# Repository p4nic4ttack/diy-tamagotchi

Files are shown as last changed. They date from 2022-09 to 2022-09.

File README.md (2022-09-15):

# DIY Tamagotchi
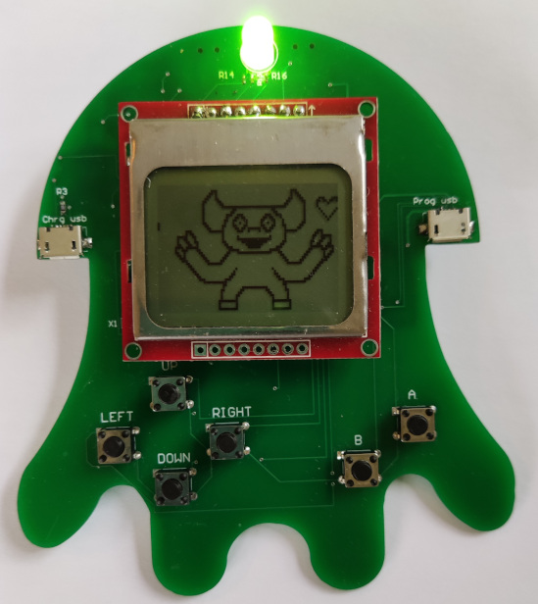
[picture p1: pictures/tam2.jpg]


## Project introduction
This project features a 'home made' DIY Tamagotchi. <br>The aim was to create a virtual pet for which the user needs to care in order to maintain its general happiness. Caring for the Tamagotchi is done by feeding and washing it on a regular basis or by playing games with it.<br>
This README.md covers the technical details of this project and the issues I ran into.
### Content
* [Main components](#main-components)
* [Software features](#software-features)
* [Hardware features](#hardware-features)
* [How does the hardware works?](#how-does-it-work-hw)
 * [Power Supply](#how-does-it-work-hw-power)
 * [Programming interface for the XC888](#how-does-it-work-hw-programming)
 * [RTC support](#how-does-it-work-hw-rtc)
 * [Hardware blockdiagram](#hw-blockdiagram)
* [Hardware issues](#hw-issues)
 * [Inductor does not let enough current pass through](#hw-issues-inductor)
 * [Battery lifetime](#hw-issues-battery)
 * [Minor issues](#hw-issues-minor)
* [How does the software works?](#how-does-it-work-sw)
 * [Software development](#how-does-it-work-sw-dev)
 * [Bitbanged interfaces](#how-does-it-work-sw-bitbanging)
 * [Interrupt based time intervals](#how-does-it-work-sw-isr)
 * [Software blockdiagram](#sw-blockdiagram)
* [Software issues](#sw-issues)
 * [Battery lifetime](#sw-issues-battery)
 * [Memory models](#sw-issues-memory)
* [Putting everything to work](#putting-it-to-work)

### Main components
The following main components were used in order to realise this:
- XC888 micro controller (8051 family)
- Nokia 5510 LCD display
- DS1307 for RTC support
- 3.7V LiPo battery
- RGB status LED
- 6 press buttons for navigation

Note that the complete component list can be found in the BOM [here](pcb-design-Altium/bom.csv).

### Software features

Technical:
 - Small Device C Compiler aka sdcc
 - Mix of assembly & C
 - Bitbanged I²C & SPI interfaces
 - Interrupt based time interval
 - Animations based on 'diffs'
 - Views (state machines)

<br>

Functional:
 - 2 types of pets
 - Time/clock
 - Emotion shown by the virtual pet and on the RGB LED
 - Sleep time between 8 pm and 9 am
 - Satisfaction/emotion depends on care
 - Feeding, washing, playing a game

### Hardware features
- XC888 micro controller (8051 family)
- LiPo powered
 - Battery charging circuit on board
 - Overcharge, overdischarge & overcurrent protection
- Reprogrammable (FT232RL using micro USB)
- RTC via DS1307 (32.76KHz)
- Navigation press buttons
- Status RGB LED
<br>
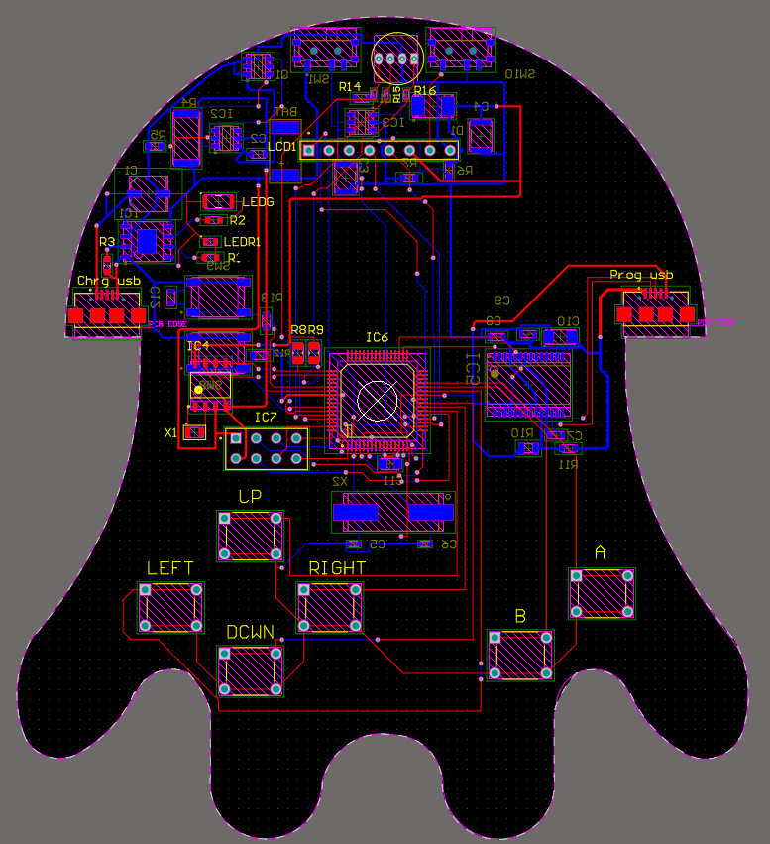
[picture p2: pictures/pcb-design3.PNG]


## How does the hardware works?

### 1. Power suppy
The circuit is powered by a 3.7V LiPo battery. Since most components need 5V to function, it was necessary to use a step-up IC (MT3608) to get 5.1V.
<br>
The battery can be charged through a micro USB port which is connected to a charging IC (TP4056). This charging IC is connected to battery protection IC (FS312F-G) which protects for overcharge and overdischarge. Note that the two necessary MOSFETS are externally attached for this.

### 2. Programming interface for the XC888
In order to program the XC888, an FT232RL is used which is connected to the right side micro USB port. For sake of simplicity two micro USB ports are present, one for Programming and one for charging. This could also be done with one micro USB port.

### 3. RTC support
RTC is done through the DS1307 IC. This IC communicates with the XC888 using I²C. Since the XC888 has no native I²C support, it was necessary to bitbang this on the XC888.<br>
Note that the SDA and SCL pins are open drains, which means that external pull up resistors are normally necessary. Since the XC888 provides internal pull ups on its pins, it wasn't necessary to provide external pull ups, although they are still there in my design.

### Hardware block diagram
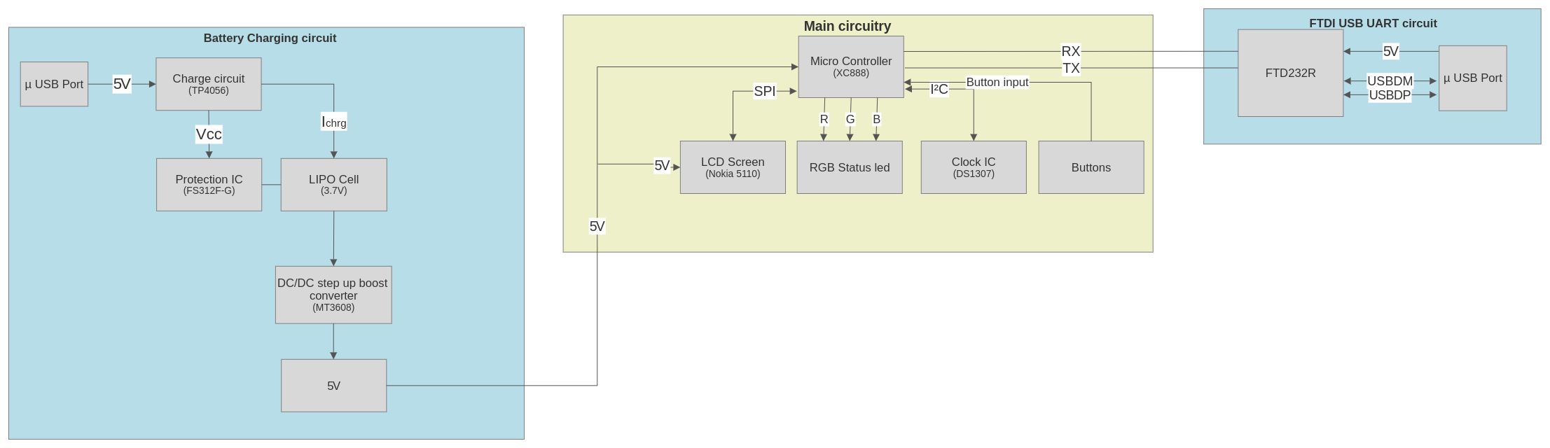
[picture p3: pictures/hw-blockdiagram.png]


(See [schematics](pcb-design-Altium/schematics.pdf))

## Hardware issues

### 1. Inductor does not let enough current pass through
When enabling the backlight of the Tamagotchi LCD screen, the inductor (L1) used in the step up circuitry does not let enough current pass. When enabling the backlight for a longer time, the inductor will start burning as seen in the pictures below:<br>
<p align="center">
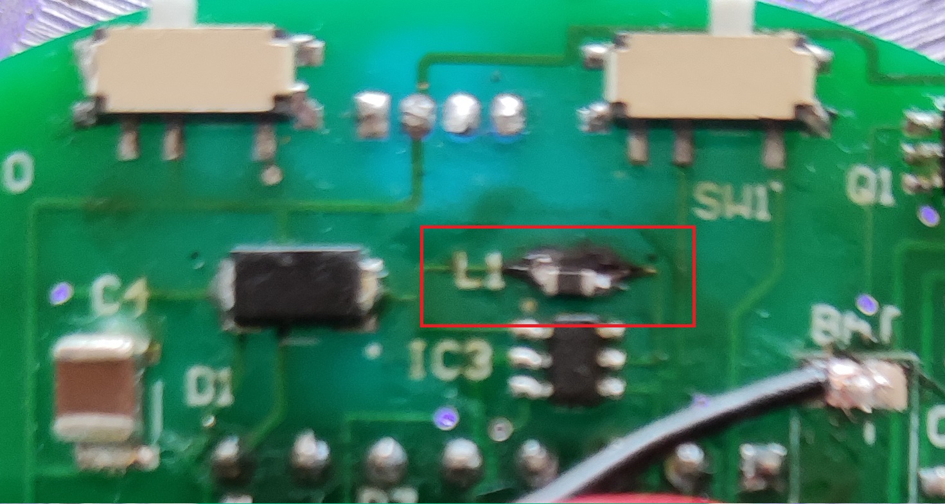
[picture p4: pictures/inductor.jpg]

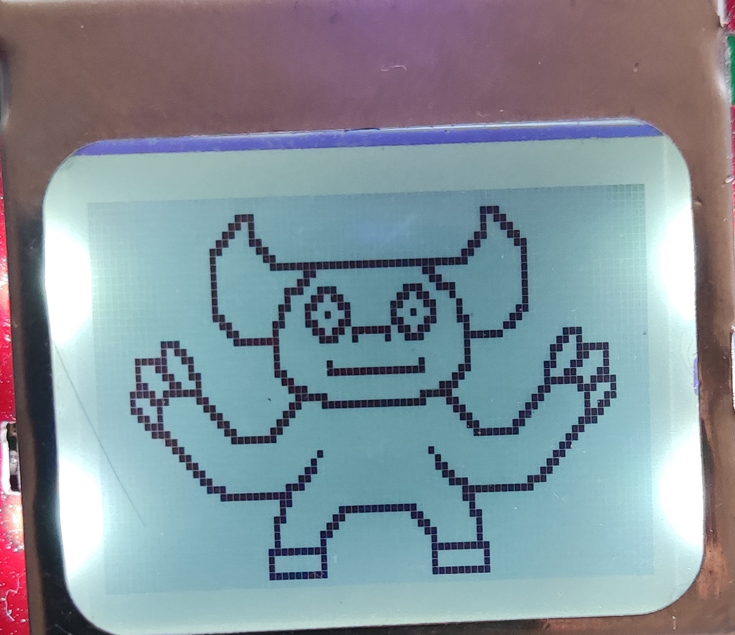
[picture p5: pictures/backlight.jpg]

</p>

### 2. Battery lifetime
A rough calculation of power dissipation in active components:
- Nokia LCD - `50mA * 5.1V (250mW)`
- RGB LED - `20mA * 2.7V (54mW)`
- XC888
 - Active mode & slowdown `14.1mA flash and (+) 11.9mA ROM * 5.1V = 132.6mW`
 - Active mode `27.2mA flash and (+) 24.3mA ROM * 5.1V= 262.65mW`
- DS1307 - `1.5mA * 5.1V (7.6mW)`

Rough estimation:
```
250mW + 54mW + 132.6mW + 7.6mW = 444.2mW
--> (±3.7V*1250mAh)/444.2mW = ±10h30
```

### 3. Minor issues
1. Forgot to take up the CR battery cell holder in my design, meaning the user needs to configure the RTC each time the Tamagotchi is restarted
2. Not enough space provided to fit most micro USB cables (had to cut part of the cable in order to fit in the micro USB port)
<p align="center">
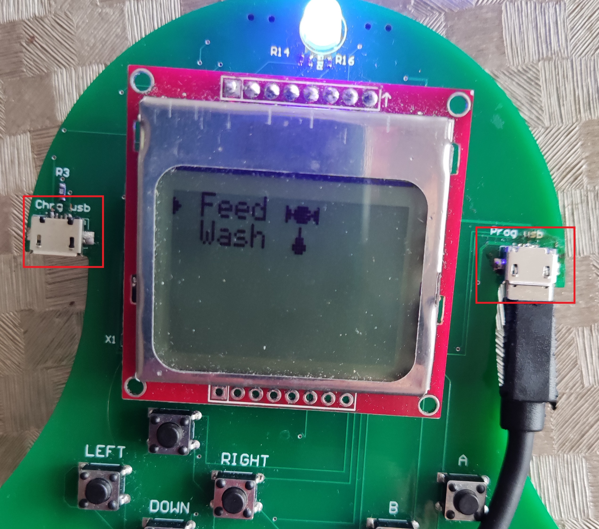
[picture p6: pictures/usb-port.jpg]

</p>

## How does the software works?

### 1. Software development
Most of the software was written in C. The more low level parts which are part of the HAL (such as drivers) were programmed in assembly, inlined in C. The compiler used in this project is Small Device C Compiler (sdcc).
<br>
In order to determine how parameters were passed from C to the inlined assembly routines, I did the following test:
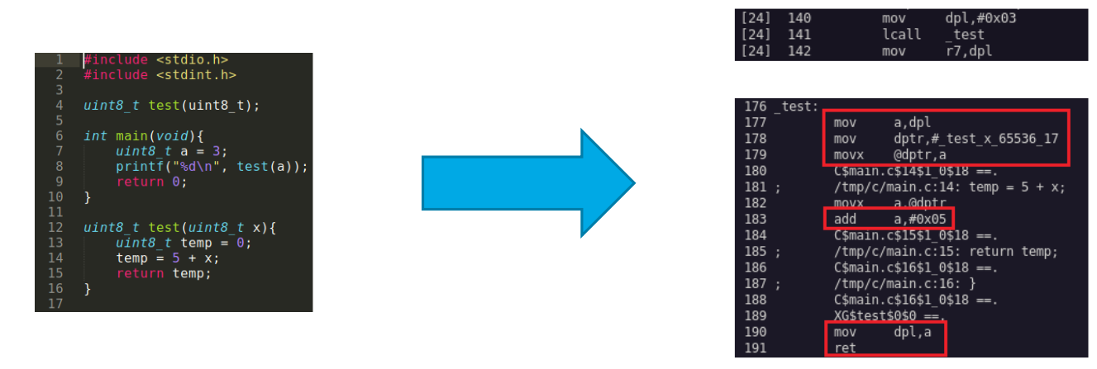
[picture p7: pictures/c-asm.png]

`sdcc -c --debug --use-stdout -V --xram-loc 0xF000 --xram-size 0x600 --code-size 0x5000 /tmp/c/main.c`
<br>
It appeared that arguments passed to a function are stored in the `dpl` register and from there on used in the function. Same goes for return values.

### 2. Bitbanged interfaces
The Tamagotchi uses I²C to allow communication between the XC888 and DS1307 RTC IC. I²C is not natively supported on the XC888, meaning that it was necessary to bitbang this. Furthermore the XC888 communicates with the LCD screen using SPI. Although the XC888 has intended SPI pins, I forgot to use these in my initial design so I used other pins for the LCD which did not support SPI, resulting in Bitbanging the SPI interface as well.
In order to bitbang these, I heavily relied on a Saleae logic analyser:
<p align="center">
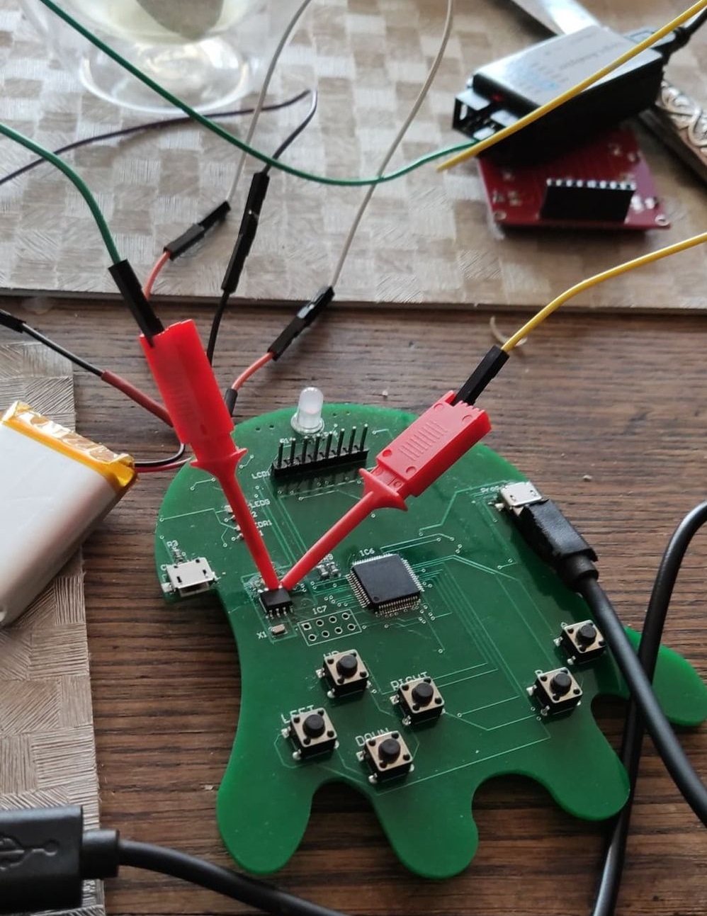
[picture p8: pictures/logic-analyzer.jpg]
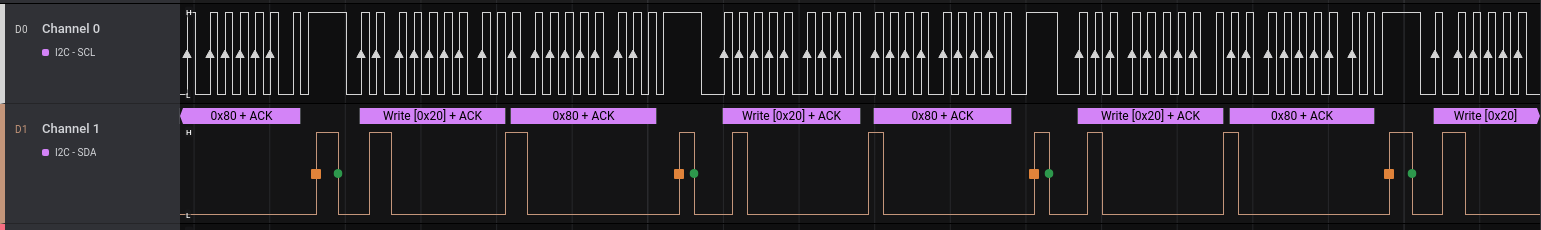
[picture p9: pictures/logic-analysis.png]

</p>

### 3. Interrupt based time intervals
Because reading the RTC IC is considered to be expensive due to the nature of bitbanging, I tried to limit the reads towards it using a 1 second interrupt interval.
```
typedef struct time_t{
        uint8_t millis;
        uint8_t seconds;
        uint8_t minutes;
}time_t;

void timer0_isr_time (void) __interrupt (TIMER0_INTERRUPT)
{
        //TIME
    static uint16_t current_count_time = 0;
    //48000 ticks = 1 sec
    if(++current_count_time == 48000){
        ticks += 1;
        current_count_time = 0;
        time.seconds += 1;
    }   
}
```
Enabling the timer was done by setting the following registers to its corresponding values:
```
void inittimer(void){
        tmod = 0b00000010; //Timer 0 8 bit autoreload
        et0 = 1; //Enable Timer 0 interrupts
        ea = 1; //Globale interrupt enable
        th0 = 6;
        tl0 = 6;
        tr0 = 1;
}
```
Only if `time.seconds == 60` the RTC is polled:
```
while(1){          
  if(time.seconds == 60){
    time.seconds = 0;
    read_rtc(&now);
    if(tam->emotion != 4 && (now.hour >= 0x20 || now.hour < 0x9)){
                        ...
    }
}
```

### Software blockdiagram
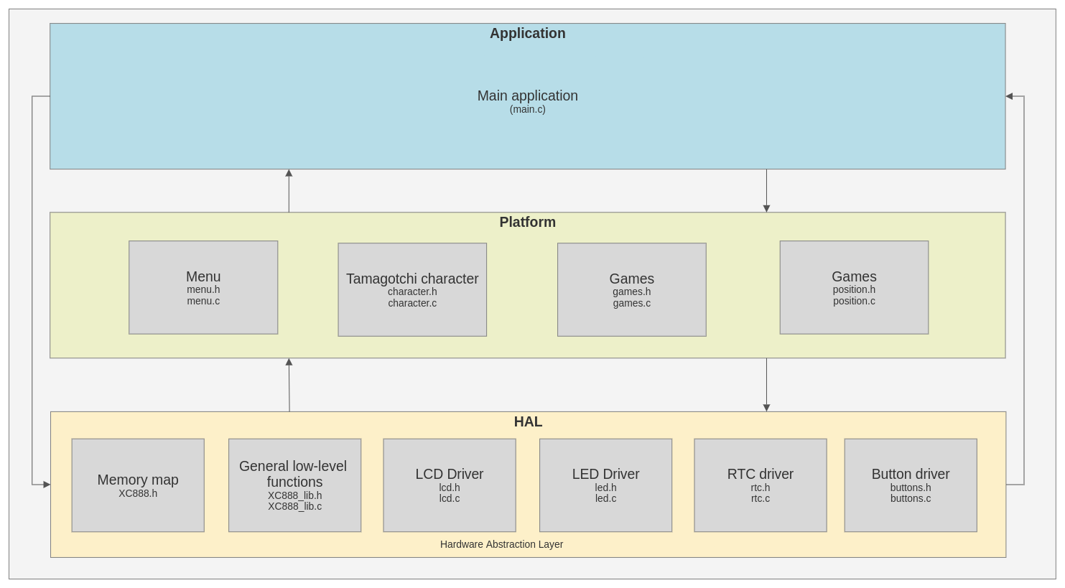
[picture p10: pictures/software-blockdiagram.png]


## Software issues

### 1. Battery life time
I attempted to address the (short) battery lifetime issue using the power saving modes of the XC888.<br>
The following was mentioned in the XC888 datasheet:
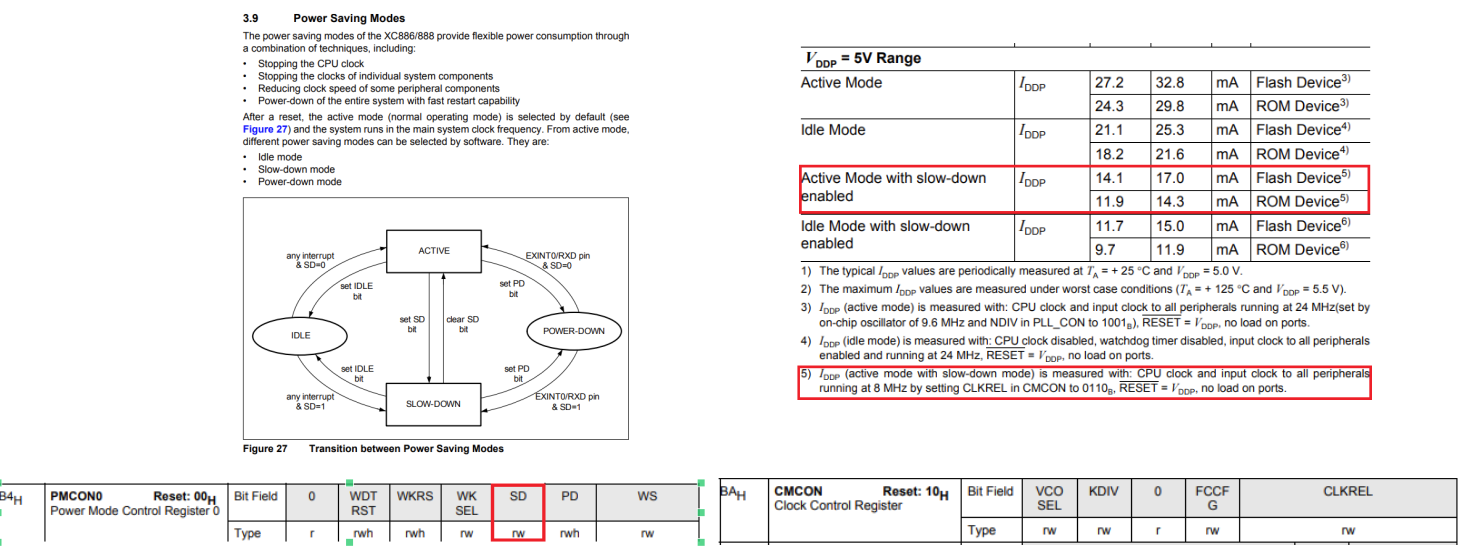
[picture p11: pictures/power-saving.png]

According to this it is possible to get into slowdown mode by forcing the CLCKREL register to 0110 and by activating the 'slowdown' (SD) bit in the pmcon register.
```
cmcon &= ~(1UL << 0);
cmcon |= 1UL << 1;
cmcon |= 1UL << 2;
cmcon &= ~(1UL << 3);

pmcon0 |= 1UL << 2;
```

### 2. Memory models
When compiling with the following command (which worked in the beginning), I started to getting errors after a while:<br>
<code>
$ sdcc --debug <b>--model-small</b> --use-stdout -V --xram-loc 0xF000 --xram-size 0x600 --code-size 0x7000 -I/home/xoreo/sdcc-Tamagotchi/ -o/home/xoreo/sdcc-Tamagotchi/main.hex /home/xoreo/sdcc-Tamagotchi/main.rel /home/xoreo/sdcc-Tamagotchi/xc888_lib.rel /home/xoreo/sdcc-Tamagotchi/led.rel /home/xoreo/sdcc-Tamagotchi/lcd.rel /home/xoreo/sdcc-Tamagotchi/buttons.rel /home/xoreo/sdcc-Tamagotchi/position.rel /home/xoreo/sdcc-Tamagotchi/character.rel /home/xoreo/sdcc-Tamagotchi/menu.rel /home/xoreo/sdcc-Tamagotchi/rtc.rel /home/xoreo/sdcc-Tamagotchi/games.rel
</code><br>
The following error was returned:<br>

<br>
Using the `--model-medium` compiler flag instead solved the problem for some extra time, until I received the next error:<br>
<br>
This forced me using the `--model-large` flag.<br>
According to the datasheet (https://usermanual.wiki/Document/sdcc20manual.1813032903/html#pf3d - page 60), `--model-large` and `--model-hughe`  are discouraged (I couldn't figure out why?)


The datasheet mentioned the following about the different memory models:
- `--model-small`:<br>Variables reside in the internal RAM / data segment
- `--model-medium`:<br>Variables reside in pdata (which is 256 bytes)
- `--model-large`:<br>Variables reside in xdata

## Putting everything to work
This repository contains everything to recreate this project. <br>In order to getting al this to work, the gerber files inside the `pcb-design-Altium` folder can be sent to your preferred PCB manufacturer. Inside the `pcb-design-Altium` folder, the Bill of Materials (BOM) can be found as well. All these components are necessary to get a working version. Once the PCB is manufactured and delivered, these can be soldered onto the PCB (which requires some SMD soldering).<br>
Once everything is put together, it is time to flash the micro controller. This can either be done by compiling the software your self (a `compile.sh` file is included which should do the job), otherwise it is also possible to use the `main.hex` file.<br>
Flashing the XC888 can be done by using the free software XC800_FLOAD (provided by Infineon).
In order to do so, select the correct COM port and `Target Device: XC888-8FF`.<br>
Note that the Tamagotchi must enter programming mode first, by pressing the 'SW9' SMD push button at the back, than the 'SW8' push button (also at the back) & (without releasing 'SW9') and than releasing both buttons. If everything is soldered correct and the right COM port is chosen, Fload should allow you to connect to your Tamagotchi in order to download the main.hex file to your Tamagotchi :)

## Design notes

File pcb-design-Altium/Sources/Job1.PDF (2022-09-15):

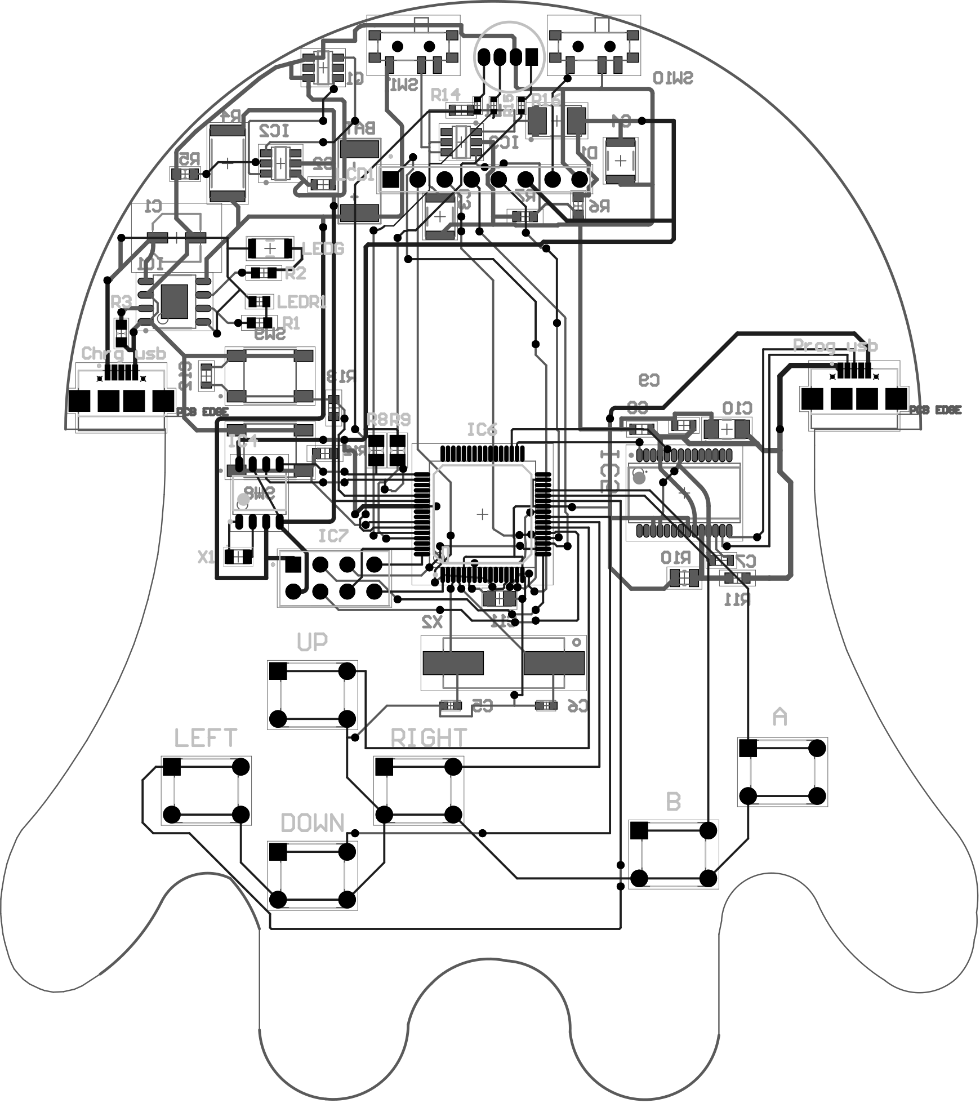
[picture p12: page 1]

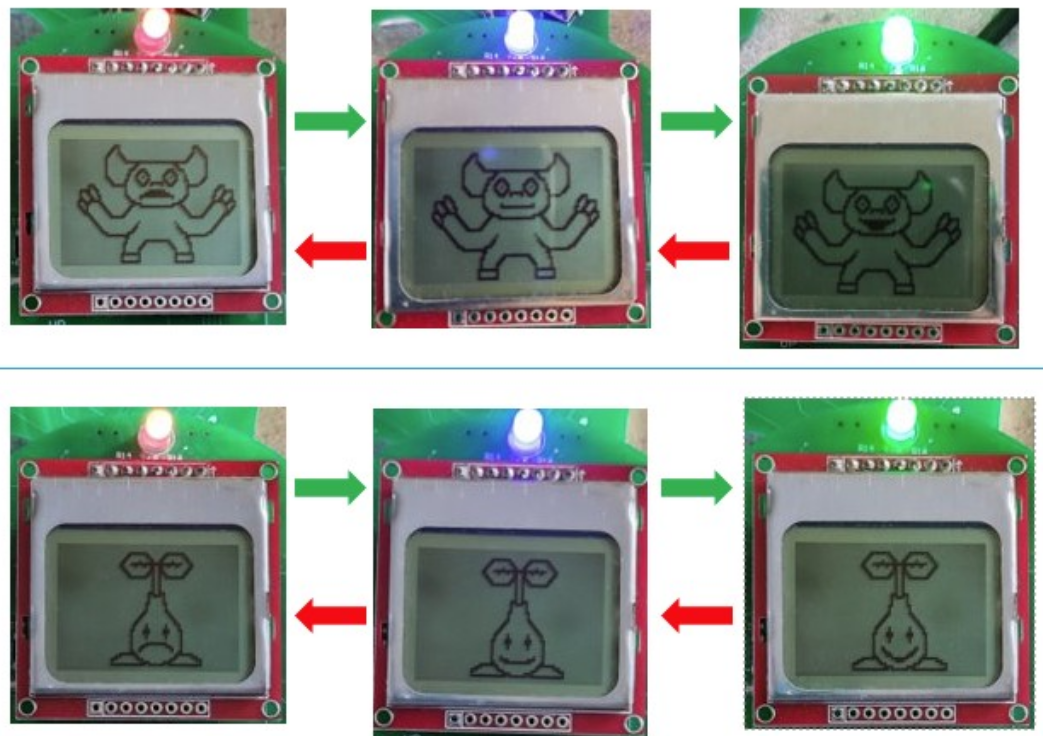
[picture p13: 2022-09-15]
pictures/statuses.png

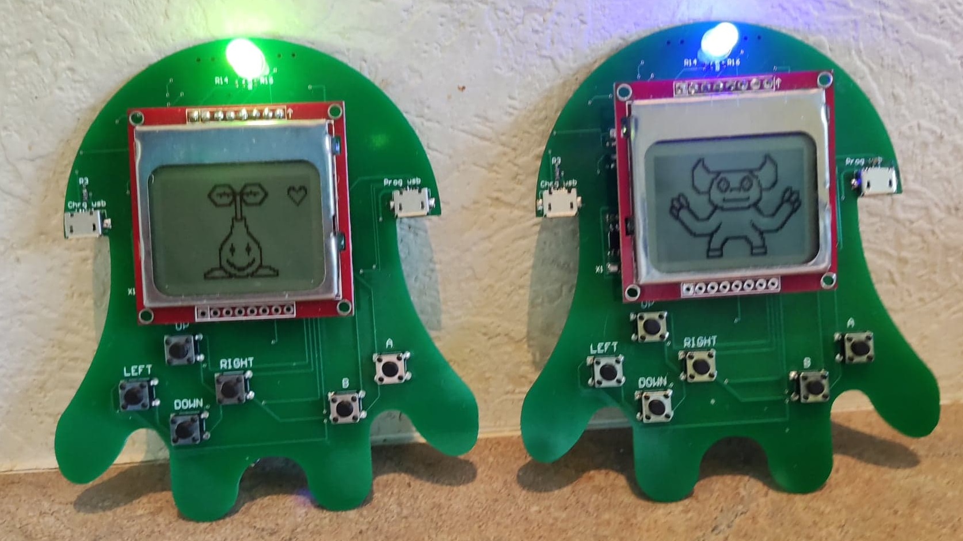
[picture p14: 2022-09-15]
pictures/tamagotchis.jpg

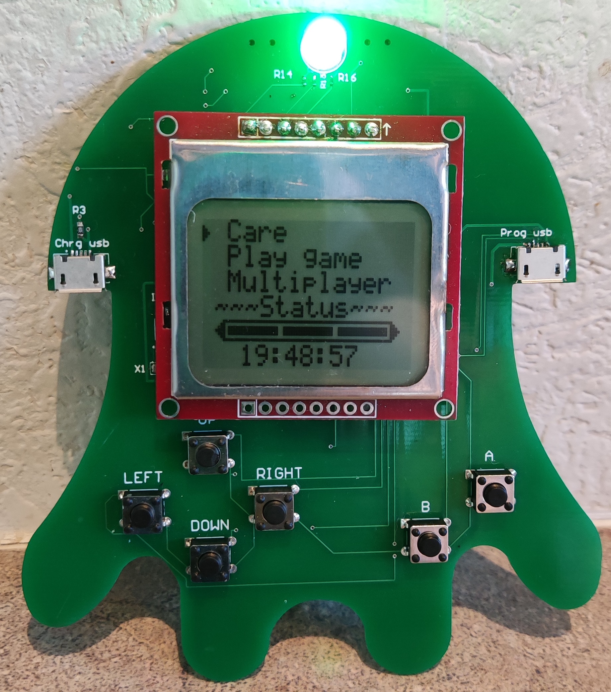
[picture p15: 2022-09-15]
pictures/menu.jpg

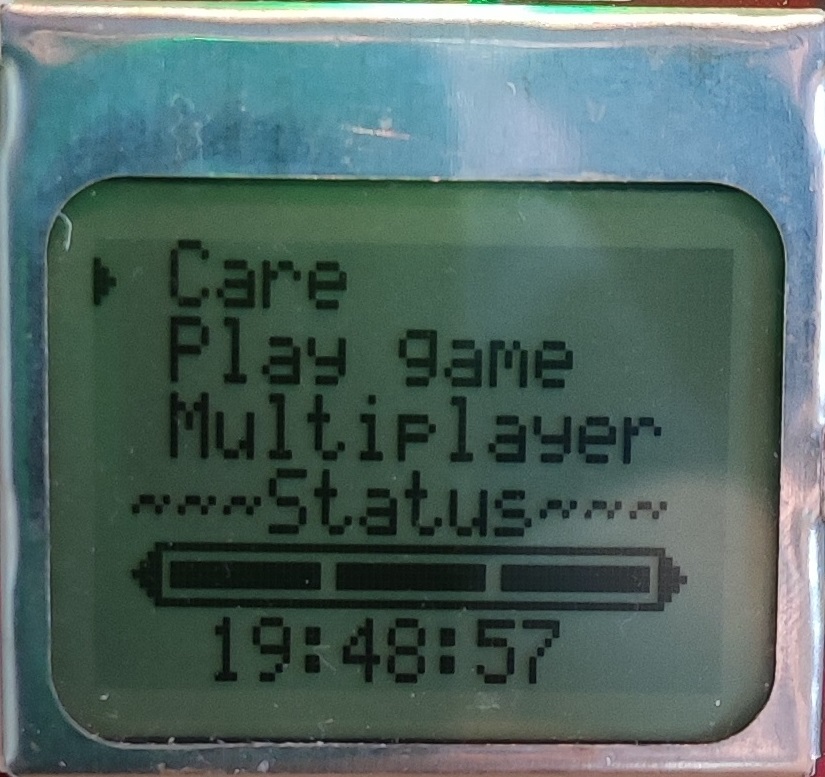
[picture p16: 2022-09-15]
pictures/menu2.jpg

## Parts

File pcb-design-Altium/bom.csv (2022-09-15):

Line # | Name | Description | Designator | Revision ID | Revision State | Revision Status | Quantity | Manufacturer 1 | Manufacturer Part Number 1 | Manufacturer Lifecycle 1 | Supplier 1 | Supplier Part Number 1 | Supplier Unit Price 1 | Supplier Subtotal 1
 | LIPO Battery |  | BAT |  | Not managed |  | 1
 | 10µF | RUBYCON - 35TZV10M4X6.1 - KONDENSATOR, 10µF, 35V, RADIAL, SMD | C1 |  | Not managed |  | 1 | Rubycon | 35TZV10M4X6.1 | Volume Production | Newark | 08X5009
 | 0.1µF/100nF | Cap Ceramic 0.1uF 25V X7R 10% Pad SMD 0603 125C T/R | C2, C7, C8, C9, C12 |  | Not managed |  | 5 | Multicomp | MC0603B104K250CT | Volume Production | Newark | 94W8728
 | 22µF | 1210 22 uF 10 V ±10 % Tolerance X7R Surface Mount Multilayer Ceramic Capacitor | C3, C4 |  | Not managed |  | 2 | Kyocera AVX | 1210ZC226KAT2A | Volume Production | Newark | 95W9441
 | 33pF | Cap Ceramic 33pF 50V C0G 5% Pad SMD 0402 125°C Ultra Low ESR T/R | C5, C6 |  | Not managed |  | 2 | Johanson | 500R07S330JV4T | Volume Production | Newark | 51Y5225
 | 4.7µF | Cap Tant Solid 4.7uF 16V UA CASE 10% (3.2 X 1.6 X 1.2mm) Inward L SMD 3216-12 4 Ohm 125C T/R | C10 |  | Not managed |  | 1 |  |  |  | RSComponents | 1882042
 | 220nF | 0805 C 220nF Ceramic Multilayer Capacitor; 50 VDC; +125degC; X7R Dielec; +/-10% | C11 |  | Not managed |  | 1 | KEMET | C0805C224K5RACTU | Volume Production | RSComponents | 8029927
 | SS34 | DIODE SCHOTTKY 40V 3A DO214AB | D1 |  | Not managed |  | 1 |  |  |  | RSComponents
 | TP4056 |  | IC1 |  | Not managed |  | 1
 | FS312F-G | Lithium battery protection IC | IC2 |  | Not managed |  | 1
 | MT3608 | Voltage regulator | IC3 |  | Not managed |  | 1
 | DS1307 | IC RTC SERIAL 512K IND 8-SOIC | IC4 |  | Not managed |  | 1 | Maxim | DS1307ZNTR | Volume Production | Digi-Key | DS1307ZN+T&R-ND
 | FT232RL | Usb Interface Ics Usb to Serial Uart 28 Pin SSOP | IC5 |  | Not managed |  | 1 | FTDI | FT232RL | Volume Production | RSComponents | 0406580
 | XC888 | MCU 8-Bit XC800 8051 CISC 32KB Flash 2.5V/5V 64-Pin LQFP T/R | IC6 |  | Not managed |  | 1 | Infineon | XC8888FFI5VACFXUMA1 | Not Recommended for New Design | Digi-Key | XC8888FFI5VACFXUMA1TR-ND
 | NRF24L01 |  | IC7 |  | Not managed |  | 1
 | 22µH | Inductor Power Shielded Multi-Layer 22uH 20% 2MHz Ferrite 0.05A 2.145Ohm DCR 0603 T/R | L1 |  | Not managed |  | 1 | TDK | MLZ1608N220LT000 | Volume Production | Arrow Electronics | MLZ1608N220LT000
 | Nokia LCD | Nokia 5110 LCD | LCD1 |  | Not managed |  | 1
 | RGB LED | Hyper Red/Green/Blue 50º Water Clear Full Color LED Lamp - T-1 3/4 | LED1 |  | Not managed |  | 1 | Kingbright | WP154A4SUREQBFZGC | Volume Production | Digi-Key | 754-1615-ND
 | LEDG | LED Uni-Color SB. Green 565nm 2-Pin Chip LED T/R | LEDG |  | Not managed |  | 1 | Kingbright | KPT-3216SGC | Volume Production | RSComponents | 8610204P
 | LEDR | Led, SMD, Red, 180MCD, 633NM | LEDR1 |  | Not managed |  | 1 | Osram Opto | LSQ976-Z | Volume Production | Avnet | LSQ976-Z
 | FS8205 | Dual N-Channel Enhancement Mode Power MOSFET | Q1 |  | Not managed |  | 1
 | 1K | 1KO ±1% 1/8W ±100ppm/? 0603 | R1, R2, R7 |  | Not managed |  | 3 | KOA Speer | RK73H1JTTD1001F | Volume Production | Arrow Electronics | RK73H1JTTD1001F
 | 2K | 2000O ± 1.00% 0.1W ± 100ppm/? 0603 | R3, R5 |  | Not managed |  | 2 | Yageo | RC0603FR-072KL | Volume Production | RSComponents | 1995523
 | 100 | Res Thick Film 2512 100 Ohm 1% 2W ±100ppm/C Pad SMD T/R | R4 |  | Not managed |  | 1 | TE Connectivity | CRGP2512F100R |  | RSComponents | 1764326
 | 7.5K | 7500O ± 1.00% 0.1W ± 100ppm/? 0603 | R6 |  | Not managed |  | 1 | Yageo | RC0603FR-077K5L | Volume Production | Newark | 68R0113
 | RC0805FR-0710KL | Chip Resistor, 10 KOhm, +/- 1%, 0.125 W, -55 to 155 degC, 0805 (2012 Metric), RoHS, Tape and Reel | R8, R9 |  | Unknown server |  | 2 | Yageo | RC0805FR-0710KL | Volume Production
 | 10K | Res SMD 0805 10K 1% 0.125W T.C.100PPM | R10 |  | Not managed |  | 1 | Yageo | RC0805FR-0710KL | Volume Production | RSComponents | 6185163
 | 4K7 R | Surface Mount Metal Film Resistor, Pcf Series, 4.7 Kohm, 63 Mw, - 0.1%, 75 V Rohs Compliant: Yes | R11, R12, R13 |  | Not managed |  | 3 | TT Welwyn | PCF0603P-R-4K7-BT1 | Volume Production | Newark | 61M8292
 | 270R | Res Thick Film 0402 270 Ohm 1% 0.063W(1/16W) ±100ppm/C Pad SMD T/R | R14, R15, R16 |  | Not managed |  | 3 | TE Connectivity | CRG0402F270R | Volume Production | Newark | 95W7454
 | Toggle Switch | C&K SK-12D07-VG 3 NS Switches > Slide > Miniature > Mini R/A Slide | SW1, SW10 |  | Not managed |  | 2 | ITT C&K | SK12D07VG3NS |  | Digi-Key | SK12D07VG3NS-ND
 | Push button | Switch Tactile N.O. SPST Round Button PC Pins 0.02A 15VDC 2.6N Thru-Hole Bulk | SW2, SW3, SW4, SW5, SW6, SW7 |  | Not managed |  | 6 | Panasonic | EVQ-PAG05R |  | RSComponents | 7561543P
 | SMD button | Switch Tactile N.O. SPST Round Button J-Bend 0.02A 15VDC 2.6N SMD Embossed Tape | SW8, SW9 |  | Not managed |  | 2 | Panasonic | EVQ-PLMA15 | Volume Production | Newark | 27AC5577
 | 61300411121 | CONN HEADER 4 POS 2.54 | USB1 |  | Not managed |  | 1 | Wurth Electronics | 61300411121 | Volume Production | RSComponents | 8281594
 | USB header | CONN HEADER 4 POS 2.54 | USB2 |  | Not managed |  | 1 | Wurth Electronics | 61300411121 | Volume Production | RSComponents | 8281594
 | 32.76 KHZ | Crystal, FC-12M, 32.768 Khz, 12.5 Pf | X1 |  | Not managed |  | 1 | Epson | X1A0000610003 FC-12M 32.768KHZ 12.5PF | Volume Production | Farnell | 1907468
 | 11.0592MHz | Crystal 11.0592MHz 16pF 2-Pin HC-49/U Loose | X2 |  | Not managed |  | 1 | Multicomp | HC49SM-11.0592-30-50-60-16-ATF | Volume Production | Newark | 33P6975

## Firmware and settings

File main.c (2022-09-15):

#include <xc888_lib.h>
#include <xc888.h>
#include <led.h>
#include <lcd.h>
#include <buttons.h>
#include <position.h>
#include <character.h>
#include <stdbool.h>
#include <menu.h>
#include <rtc.h>
#include <games.h>

#include <stdio.h>
#include <string.h>
#include <stdlib.h>

#define NUMBER_OF_DIGITS 16

//VIEWS
typedef enum views {TAMA, MENU, TIME_MENU, CARE_MENU, GAME_MENU} View;



//TIME
void inittimer(void);

typedef struct time_t{
        uint8_t millis;
        uint8_t seconds;
        uint8_t minutes;
}time_t;

static rtc_t now;
static uint16_t ticks = 0;
static time_t time = {0,0,0};
static Tamagotchi *tam;
static uint8_t random_hours;
static uint8_t prev_emotion;

void timer0_isr_time (void) __interrupt (TIMER0_INTERRUPT) 
{
	//TIME
	static uint16_t current_count_time = 0;
    if(++current_count_time == 48000){
    	ticks += 1;
        current_count_time = 0;
        time.seconds += 1;
    }	
}

void main (void){

	//Allocating space for menu's & tamagotchi character
	tam = (Tamagotchi*)malloc(sizeof(Tamagotchi));
	Menu *main = (Menu*)malloc(sizeof(Menu));
	Tamagotchi *tam = (Tamagotchi*)malloc(sizeof(Tamagotchi));
	Time_Menu *time_menu = (Time_Menu*)malloc(sizeof(Time_Menu));
	Menu *care = (Menu*)malloc(sizeof(Menu));
	Menu *games = (Menu*)malloc(sizeof(Menu));
	View view = TIME_MENU;
	//cmcon &= ~(1UL << 0); 
	//cmcon |= 1UL << 1;
	//cmcon |= 1UL << 2;
	//cmcon &= ~(1UL << 3); // CLCKREL naar 0110
	//Inits
	initdisp();
	init_buttons();
	inittimer();
	initleds();
	clear_screen();
	init_main_menu(main);
	init_time_menu(time_menu);
	init_care_menu(care);
	init_game_menu(games);

	initiic();
	init_rtc();
	srand((unsigned int)get_second()*100);

	time_t cur_time = {0,0};

	random_hours = get_random_between(1, 3);
	while(1){
		
		//pcon |= 1UL << 0;
		if(time.seconds == 60){
			//pmcon0 |= 1UL << 1;
			//pcon |= 1UL << 0;
	    	time.seconds = 0;
	    	read_rtc(&now);
	    	if(tam->emotion != 4 && (now.hour >= 0x20 || now.hour < 0x9)){
	    		clear_screen();
	        	prev_emotion = tam->emotion;
	        	set_emotion(tam, 4);
	        }
	        if(now.hour == 9 && now.min == 1){
	        	set_emotion(tam,prev_emotion);
	        }
	        if(tam->emotion != 4 && (now.hour - tam->last_interaction) > random_hours){
	        	sadder(tam);
	        	tam->last_interaction = now.hour;
	        	random_hours = get_random_between(1,3); 
	        }
	        clear_screen();
    	}
 
		if(view==TAMA){	
			draw_tamagotchi(tam);
			if(time.seconds - cur_time.seconds == 1 && get_emotion(tam) != 4){
				cur_time.seconds = time.seconds;
				move(tam);
				
			}
			if(cur_time.seconds > time.seconds)
				cur_time.seconds = time.seconds-1;
			if(check_button_pressed(A)){
				view = MENU;
				clear_screen();
			}
		}

		if(view == MENU){
			read_rtc(&now);
			draw_menu(main, tam->emotion,&now);

			if(check_button_pressed(A) && get_emotion(tam) != 4){
				if(main->choice_idx == 0)
					view = CARE_MENU;
				if(main->choice_idx == 1)
					view = GAME_MENU;
				clear_screen();
			}

			if(check_button_pressed(UP)){
				decrement_choice(main,3);

			}
			if(check_button_pressed(DOWN)){
				increment_choice(main,3);
			}
			if(check_button_pressed(B)){
				view = TAMA;
				cur_time.seconds = 0;
				time.seconds = 0;
				clear_screen();
			}
		}

		if(view==CARE_MENU){
			draw_care_menu(care);
			if(check_button_pressed(DOWN)){
				increment_choice(care,2);
			}
			if(check_button_pressed(UP)){
				decrement_choice(care,2);
			}
			if(check_button_pressed(A)){
				if(care->choice_idx==0){
					food_animation(tam);
					happier(tam);
				}
				if(care->choice_idx==1){
					wash_animation();
					uint8_t x = get_random_between(1,6);
					if(x == 3)
						happier(tam);
				}
			}
			if(check_button_pressed(B)){
				view = MENU;
				cur_time.seconds = time.seconds-1;
				clear_screen();
			}
		}

		if(view == GAME_MENU){
			draw_game_menu(games);
			if(check_button_pressed(A)){
				if(games->choice_idx==0){
					if(move_game(tam)==1)
						happier(tam);
				}
			}
			if(check_button_pressed(B)){
				view = MENU;
				clear_screen();
			}
		}

		if(view == TIME_MENU){
			draw_time_menu(time_menu);
			if(check_button_pressed(RIGHT)){
				clear_time_choice(time_menu->choice_idx);
				time_menu->choice_idx+=1;
				if(time_menu->choice_idx == 3)
					time_menu->choice_idx = 0;
			}
			if(check_button_pressed(LEFT)){
				clear_time_choice(time_menu->choice_idx);
				if(time_menu->choice_idx == 0)
					time_menu->choice_idx = 3;
				time_menu->choice_idx -= 1;

			}
			if(check_button_pressed(UP)){
				time_menu->items[time_menu->choice_idx].time_element += 1;
				if(time_menu->choice_idx==0 && time_menu->items[time_menu->choice_idx].time_element==24)
					time_menu->items[time_menu->choice_idx].time_element = 0;
				if((time_menu->choice_idx==1 || time_menu->choice_idx==2) && time_menu->items[time_menu->choice_idx].time_element==60)
					time_menu->items[time_menu->choice_idx].time_element = 0;
			}
			if(check_button_pressed(DOWN)){
				if(time_menu->choice_idx==0 && time_menu->items[time_menu->choice_idx].time_element==0)
					time_menu->items[time_menu->choice_idx].time_element = 24;
				if((time_menu->choice_idx==1 || time_menu->choice_idx==2) && time_menu->items[time_menu->choice_idx].time_element==0)
					time_menu->items[time_menu->choice_idx].time_element = 60;
				time_menu->items[time_menu->choice_idx].time_element -= 1;
			}
			if(check_button_pressed(A)){
				rtc_t date = {time_menu->items[2].time_element, time_menu->items[1].time_element, time_menu->items[0].time_element, 1, 0x01,0x01,0x16};
				init_date(&date);
				free(time_menu);
				init_tamagotchi(tam);
				view = TAMA;
				time.seconds = 0;
				time.millis = 0;
				time.minutes = 0;
				pmcon0 |= 1UL << 2;
			}
		}
	}
}

//TIMER
void inittimer(void){
	tmod = 0b00000010; //Timer 0 int 8 bit autoreload mode
	et0 = 1; //timer 0 interrupts enablen
	ea = 1; //globale interrupts enablen
	th0 = 6; //Interrupt na 250 clock ticks
	tl0 = 6; 
	tr0 = 1; // Start timer 0
}

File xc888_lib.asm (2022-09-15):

;--------------------------------------------------------
; File Created by SDCC : free open source ANSI-C Compiler
; Version 4.0.0 #11528 (Linux)
;--------------------------------------------------------
	.module xc888_lib
	.optsdcc -mmcs51 --model-large
	
;--------------------------------------------------------
; Public variables in this module
;--------------------------------------------------------
	.globl _rand
	.globl _ri1
	.globl _ti1
	.globl _rb81
	.globl _tb81
	.globl _ren1
	.globl _sm21
	.globl _sm11
	.globl _sm01
	.globl _cd_bsy
	.globl _error
	.globl _eoc
	.globl _int_en
	.globl _dmap
	.globl _keepx
	.globl _keepy
	.globl _keepz
	.globl _irdy
	.globl _ierr
	.globl _bsy
	.globl _rwen
	.globl _can_bsy
	.globl _auad0
	.globl _auad1
	.globl _v0
	.globl _v1
	.globl _v2
	.globl _v3
	.globl _cprl2
	.globl _ct2
	.globl _tr2
	.globl _exen2
	.globl _exf2
	.globl _tf2
	.globl _p4_od_0
	.globl _p4_od_1
	.globl _p4_od_2
	.globl _p4_od_3
	.globl _p4_od_4
	.globl _p4_od_5
	.globl _p4_od_6
	.globl _p4_od_7
	.globl _p3_od_0
	.globl _p3_od_1
	.globl _p3_od_2
	.globl _p3_od_3
	.globl _p3_od_4
	.globl _p3_od_5
	.globl _p3_od_6
	.globl _p3_od_7
	.globl _p1_od_0
	.globl _p1_od_1
	.globl _p1_od_2
	.globl _p1_od_3
	.globl _p1_od_4
	.globl _p1_od_5
	.globl _p1_od_6
	.globl _p1_od_7
	.globl _p0_od_0
	.globl _p0_od_1
	.globl _p0_od_2
	.globl _p0_od_3
	.globl _p0_od_4
	.globl _p0_od_5
	.globl _p0_od_6
	.globl _p0_od_7
	.globl _p4_altsel0_0
	.globl _p4_altsel0_1
	.globl _p4_altsel0_2
	.globl _p4_altsel0_3
	.globl _p4_altsel0_4
	.globl _p4_altsel0_5
	.globl _p4_altsel0_6
	.globl _p4_altsel0_7
	.globl _p3_altsel0_0
	.globl _p3_altsel0_1
	.globl _p3_altsel0_2
	.globl _p3_altsel0_3
	.globl _p3_altsel0_4
	.globl _p3_altsel0_5
	.globl _p3_altsel0_6
	.globl _p3_altsel0_7
	.globl _p1_altsel0_0
	.globl _p1_altsel0_1
	.globl _p1_altsel0_2
	.globl _p1_altsel0_3
	.globl _p1_altsel0_4
	.globl _p1_altsel0_5
	.globl _p1_altsel0_6
	.globl _p1_altsel0_7
	.globl _p0_altsel0_0
	.globl _p0_altsel0_1
	.globl _p0_altsel0_2
	.globl _p0_altsel0_3
	.globl _p0_altsel0_4
	.globl _p0_altsel0_5
	.globl _p0_altsel0_6
	.globl _p0_altsel0_7
	.globl _p4_pudsel_0
	.globl _p4_pudsel_1
	.globl _p4_pudsel_2
	.globl _p4_pudsel_3
	.globl _p4_pudsel_4
	.globl _p4_pudsel_5
	.globl _p4_pudsel_6
	.globl _p4_pudsel_7
	.globl _p3_pudsel_0
	.globl _p3_pudsel_1
	.globl _p3_pudsel_2
	.globl _p3_pudsel_3
	.globl _p3_pudsel_4
	.globl _p3_pudsel_5
	.globl _p3_pudsel_6
	.globl _p3_pudsel_7
	.globl _p2_pudsel_0
	.globl _p2_pudsel_1
	.globl _p2_pudsel_2
	.globl _p2_pudsel_3
	.globl _p2_pudsel_4
	.globl _p2_pudsel_5
	.globl _p2_pudsel_6
	.globl _p2_pudsel_7
	.globl _p1_pudsel_0
	.globl _p1_pudsel_1
	.globl _p1_pudsel_2
	.globl _p1_pudsel_3
	.globl _p1_pudsel_4
	.globl _p1_pudsel_5
	.globl _p1_pudsel_6
	.globl _p1_pudsel_7
	.globl _p0_pudsel_0
	.globl _p0_pudsel_1
	.globl _p0_pudsel_2
	.globl _p0_pudsel_3
	.globl _p0_pudsel_4
	.globl _p0_pudsel_5
	.globl _p0_pudsel_6
	.globl _p0_pudsel_7
	.globl _scl
	.globl _sda
	.globl _sclk
	.globl _sdin
	.globl _dc
	.globl _rst
	.globl _cs
	.globl _p5_data_0
	.globl _p5_data_1
	.globl _p5_data_2
	.globl _p5_data_3
	.globl _p5_data_4
	.globl _p5_data_5
	.globl _p5_data_6
	.globl _p5_data_7
	.globl _p4_data_0
	.globl _p4_data_1
	.globl _p4_data_2
	.globl _p4_data_3
	.globl _p4_data_4
	.globl _p4_data_5
	.globl _p4_data_6
	.globl _p4_data_7
	.globl _p3_data_0
	.globl _p3_data_1
	.globl _p3_data_2
	.globl _p3_data_3
	.globl _p3_data_4
	.globl _p3_data_5
	.globl _p3_data_6
	.globl _p3_data_7
	.globl _p2_data_0
	.globl _p2_data_1
	.globl _p2_data_2
	.globl _p2_data_3
	.globl _p2_data_4
	.globl _p2_data_5
	.globl _p2_data_6
	.globl _p2_data_7
	.globl _p1_data_0
	.globl _p1_data_1
	.globl _p1_data_2
	.globl _p1_data_3
	.globl _p1_data_4
	.globl _p1_data_5
	.globl _p1_data_6
	.globl _p1_data_7
	.globl _p0_data_0
	.globl _p0_data_1
	.globl _p0_data_2
	.globl _p0_data_3
	.globl _p0_data_4
	.globl _p0_data_5
	.globl _p0_data_6
	.globl _p0_data_7
	.globl _padc
	.globl _pssc
	.globl _px2
	.globl _pxm
	.globl _pccip0
	.globl _pccip1
	.globl _pccip2
	.globl _pccip3
	.globl _eadc
	.globl _essc
	.globl _ex2
	.globl _exm
	.globl _eccip0
	.globl _eccip1
	.globl _eccip2
	.globl _eccip3
	.globl _p
	.globl _f1
	.globl _ov
	.globl _rs0
	.globl _rs1
	.globl _f0
	.globl _ac
	.globl _cy
	.globl _px0
	.globl _pt0
	.globl _px1
	.globl _pt1
	.globl _ps
	.globl _pt2
	.globl _ex0
	.globl _et0
	.globl _ex1
	.globl _et1
	.globl _es
	.globl _et2
	.globl _ea
	.globl _ri
	.globl _ti
	.globl _rb8
	.globl _tb8
	.globl _ren
	.globl _sm2
	.globl _sm1
	.globl _sm0
	.globl _it0
	.globl _ie0
	.globl _it1
	.globl _ie1
	.globl _tr0
	.globl _tf0
	.globl _tr1
	.globl _tf1
	.globl _mmwr2
	.globl _mmwr1
	.globl _hwbpdr
	.globl _hwbpsr
	.globl _mmdr
	.globl _mmicr
	.globl _mmbpcr
	.globl _mmsr
	.globl _mmcr
	.globl _mmcr2
	.globl _fdres1
	.globl _fdstep1
	.globl _fdcon1
	.globl _bg1
	.globl _bcon1
	.globl _sbuf1
	.globl _scon1
	.globl _t21_t2h
	.globl _t21_t2l
	.globl _t21_rc2h
	.globl _t21_rc2l
	.globl _t21_t2mod
	.globl _t21_t2con
	.globl _wdth
	.globl _wdtl
	.globl _wdtwinb
	.globl _wdtrel
	.globl _wdtcon
	.globl _cd_con
	.globl _cd_statc
	.globl _cd_cordzh
	.globl _cd_cordzl
	.globl _cd_cordyh
	.globl _cd_cordyl
	.globl _cd_cordxh
	.globl _cd_cordxl
	.globl _mr5
	.globl _md5
	.globl _mr4
	.globl _md4
	.globl _mr3
	.globl _md3
	.globl _mr2
	.globl _md2
	.globl _mr1
	.globl _md1
	.globl _mr0
	.globl _md0
	.globl _mducon
	.globl _mdustat
	.globl _data3
	.globl _data2
	.globl _data1
	.globl _data0
	.globl _adh
	.globl _adl
	.globl _adcon
	.globl _ssc_brh
	.globl _ssc_brl
	.globl _ssc_rbl
	.globl _ssc_tbl
	.globl _ssc_conh
	.globl _ssc_conl
	.globl _ssc_pisel
	.globl _ccu6_cmpstath
	.globl _ccu6_cmpstatl
	.globl _ccu6_t13h
	.globl _ccu6_t13l
	.globl _ccu6_t12h
	.globl _ccu6_t12l
	.globl _ccu6_pisel2
	.globl _ccu6_pisel0h
	.globl _ccu6_pisel0l
	.globl _ccu6_ish
	.globl _ccu6_isl
	.globl _ccu6_mcmouth
	.globl _ccu6_mcmoutl
	.globl _ccu6_trpctrh
	.globl _ccu6_trpctrl
	.globl _ccu6_modctrh
	.globl _ccu6_modctrl
	.globl _ccu6_tctr2h
	.globl _ccu6_tctr2l
	.globl _ccu6_mcmctr
	.globl _ccu6_pslr
	.globl _ccu6_issh
	.globl _ccu6_issl
	.globl _ccu6_inph
	.globl _ccu6_inpl
	.globl _ccu6_ienh
	.globl _ccu6_ienl
	.globl _ccu6_t12mselh
	.globl _ccu6_t12msell
	.globl _ccu6_cc62rh
	.globl _ccu6_cc62rl
	.globl _ccu6_cc61rh
	.globl _ccu6_cc61rl
	.globl _ccu6_cc60rh
	.globl _ccu6_cc60rl
	.globl _ccu6_tctr0h
	.globl _ccu6_tctr0l
	.globl _ccu6_t12dtch
	.globl _ccu6_t12dtcl
	.globl _ccu6_t13prh
	.globl _ccu6_t13prl
	.globl _ccu6_t12prh
	.globl _ccu6_t12prl
	.globl _ccu6_cc63rh
	.globl _ccu6_cc63rl
	.globl _ccu6_cc62srh
	.globl _ccu6_cc62srl
	.globl _ccu6_cc61srh
	.globl _ccu6_cc61srl
	.globl _ccu6_cc60srh
	.globl _ccu6_cc60srl
	.globl _ccu6_cmpmodifh
	.globl _ccu6_cmpmodifl
	.globl _ccu6_isrh
	.globl _ccu6_isrl
	.globl _ccu6_mcmoutsh
	.globl _ccu6_mcmoutsl
	.globl _ccu6_tctr4h
	.globl _ccu6_tctr4l
	.globl _ccu6_cc63srh
	.globl _ccu6_cc63srl
	.globl _ccu6_page
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
